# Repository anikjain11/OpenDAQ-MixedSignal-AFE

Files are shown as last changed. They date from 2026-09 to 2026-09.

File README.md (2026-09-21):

# OpenDAQ-AFE: Mixed-Signal Detector Readout & DAQ Pipeline

<div align="center">




[]()

</div>

---

## 🔬 Project Overview

**OpenDAQ-AFE** is an open-source, production-grade mixed-signal data acquisition (DAQ) and detector front-end architecture. Designed for high-energy physics instrumentation, this system bridges microscopic sensor physics to real-time digital signal processing.

It takes a sub-nanosecond, femtocoulomb-level current pulse generated by a particle hit on a semiconductor sensor, processes it through an ultra-low noise analog front-end (AFE), and digitizes the signal via a high-speed path. 

---

## 📐 System Architecture & Signal Chain

    [ Semiconductor Sensor (PIN Diode / 70pF) ]
                           │ 
                           ▼ (1 pC Charge Pulse, ~1ns rise)
    [ Analog Front-End (OPA656 Charge-Sensitive Preamplifier) ]
                           │ 
                           ▼ (-900mV Step, 50us Exponential Decay)
    [ Active CR-RC Pulse Shaper with PZ Cancellation ]
                           │ 
                           ▼ (~720mV Semi-Gaussian shaping peak)
    [ High-Speed Flash ADC & FPGA RTL Engine ]
                           │ 
                           ▼ (Digitized Event Frames)
    [ CERN ROOT / Python Analysis Pipeline ]

---

## 🛠️ Repository Structure

    OpenDAQ-MixedSignal-AFE/
    ├── hardware_kicad/         # 4-Layer PCB schematics, layout (.kicad_pcb), and Gerbers
    ├── simulations_spice/      # Ngspice netlists, subcircuits (.sub), and transient analysis
    │   └── CSP_FrontEnd_Simulation/
    │       ├── opa656.sub      
    │       └── README.md       # Detailed SPICE math and slew-rate bottleneck logs
    ├── results/                # Visual proof and exported documentation
    │   ├── 01_simulations/     # Python-plotted transient response graphs
    │   ├── 02_schematics/      # PDF exports of system architecture
    │   └── 03_pcb_layout/      # 2D routing and 3D board renders
    └── README.md               # Main project overview (You are here)

---

## ⚡ Sub-System 1: Analog Front-End (CSP & Shaper)

### Mathematical Foundation
The Charge-Sensitive Preamplifier (CSP) converts input charge ($Q_{in}$) into a proportional voltage step via feedback capacitance ($C_f = 1\text{ pF}$). To prevent pulse pile-up at high event rates, the 50µs CSP decay tail is compressed using an active shaping amplifier. A Pole-Zero (PZ) cancellation network perfectly counteracts the CSP's discharge time constant.

* **Active Element:** OPA656 Wideband Unity-Gain Stable JFET-Input Op-Amp
* **Detector Capacitance:** 70 pF (PIN Photodiode emulation)
* **PZ Cancellation Resistor:** $R_{pz} = 500\text{ k}\Omega$ 

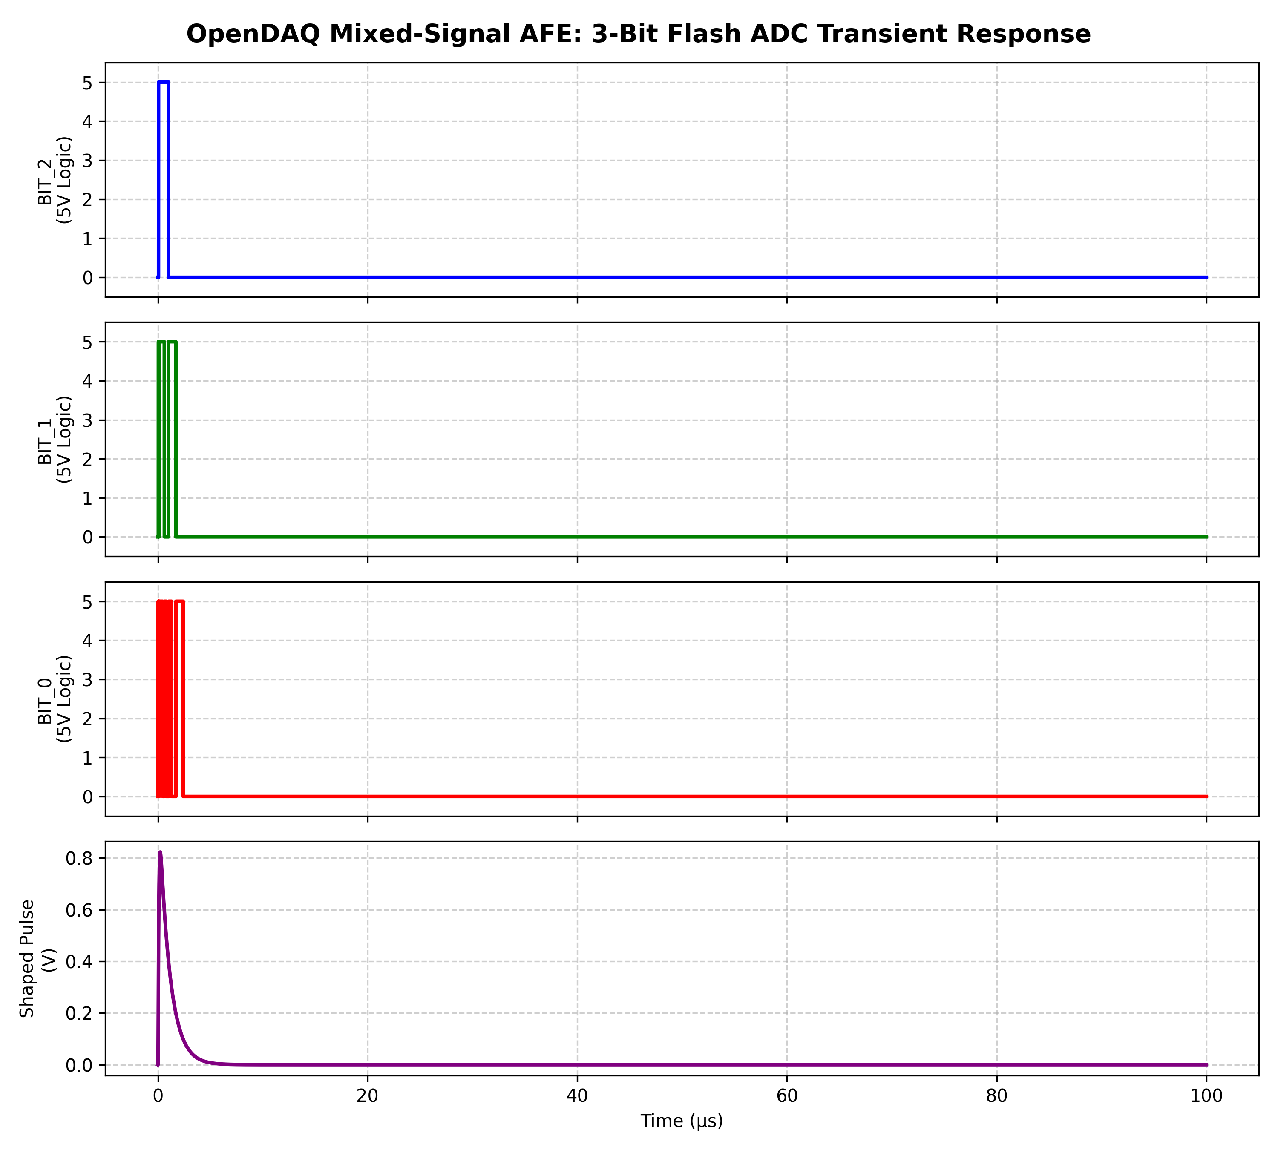
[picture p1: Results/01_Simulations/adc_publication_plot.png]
Transient Response

> *Above: Ngspice transient analysis displaying the shaper compressing the 50µs tail into a clean ~720mV semi-Gaussian peak, triggering the 3-bit Flash ADC logic (111).*
> *Note: For a deep dive into the SPICE slew-rate limitations and behavioral modeling of the ADC, [read the Simulation Notes here](simulations_spice/Simulation_README.md).*

---

## 🖨️ Sub-System 2: Physical Hardware (4-Layer PCB)

To translate the physics into silicon, the AFE was routed onto a strictly constrained, tapeout-ready physical board.

* **Dimensions:** Ultra-compact 16.7mm x 66.5mm footprint.
* **Stackup:** 4-Layer FR-4 (Signal, Ground Plane, Power Plane, Signal) for maximum EMI shielding.
* **Mixed-Signal Isolation:** Strict physical separation between the sensitive analog RF ground planes and the high-speed digital ADC return paths to protect the microvolt-level bias currents.

### Board Renders & Routing
<p align="center">
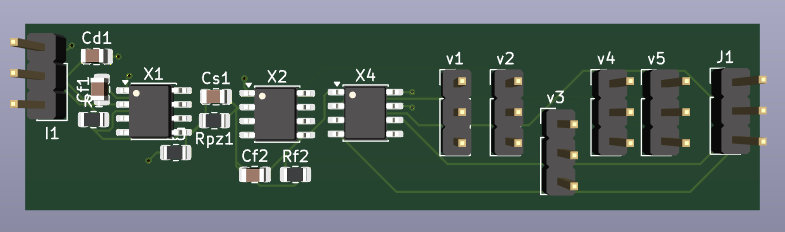
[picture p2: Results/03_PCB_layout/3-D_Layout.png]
3D PCB Render
  
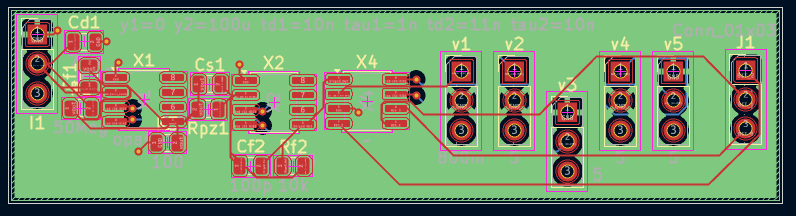
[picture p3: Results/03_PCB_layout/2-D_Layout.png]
2D Routing
  
</p>

---

## 📜 License
This hardware design and its associated software simulations are licensed under the **CERN Open Hardware Licence v2.0 - Strongly Reciprocal (CERN-OHL-S)**. See the LICENSE file for details.

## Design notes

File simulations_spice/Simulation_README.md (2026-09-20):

## 1. Charge-Sensitive Preamplifier (CSP) Front-End

### Objective
Design an ultra-low bias current analog front-end to integrate a 1 pC fast current pulse (simulating a particle strike on a 70 pF PIN photodiode) into a measurable voltage step.

### Architecture & Math
* **Op-Amp:** OPA656 (JFET input selected for low current noise).
* **Gain Stage:** Feedback capacitor $C_f = 1\text{ pF}$ designed to yield a step voltage of -1V for a 1 pC input charge.
* **Discharge Path:** Feedback resistor $R_f = 50\text{ M}\Omega$ placed in parallel to prevent saturation, setting a continuous discharge time constant of $\tau = 50\ \mu\text{s}$.

### Analysis
Transient analysis confirms the theoretical derivations. The initial charge injection drives the output to approximately -900 mV. At 50 µs, the signal decays to -330 mV, perfectly aligning with the theoretical $e^{-1}$ discharge curve.

---

## 2. Mixed-Signal Verification: 3-Bit Flash ADC

### Simulation Objective
* **Goal:** Validate the transient response of a 3-bit Flash ADC designed for the OpenDAQ Analog Front-End.
* **Input Signal:** A baseline-restored, 720 mV semi-Gaussian particle pulse peaking in roughly 1 to 2 microseconds.
* **Architecture:** An 8-resistor reference ladder (0V to 800mV) feeding 7 parallel comparators and custom digital logic bridges.

### Bottleneck 1: Component Slew Rate Limits
* **The Problem:** Initial simulations utilizing legacy LM741 op-amps resulted in a dead 0V digital output.
* **The Root Cause:** The LM741 possesses a slew rate of just 0.5V/µs. Swinging its output to trigger digital logic thresholds required upwards of 30 microseconds.
* **The Analysis:** The fast sub-microsecond particle pulse peaked and vanished long before the analog comparators could physically react.

### Bottleneck 2: Open-Loop Macro-Model Failure
* **The Problem:** Upgrading the comparators to the high-speed OPA656 (290V/µs slew rate) still yielded flatline results.
* **The Root Cause:** Vendor SPICE macro-models are mathematically optimized for closed-loop linear amplification. Forcing seven complex macro-models into an open-loop comparator topology caused internal saturation and engine convergence failures.

### The Solution: Behavioral Modeling & Visualization
* **Simulation Fix:** Replaced physical IC macro-models with mathematical arbitrary behavioral sources (`B` sources) acting as ideal comparators. This successfully decoupled the analog SPICE convergence constraints from the digital logic validation.
* **Data Extraction:** KiCad's native plotter struggled to auto-scale instantaneous 0V to 5V logic transitions. Raw transient data was exported via CSV and processed through a custom Python script (Pandas/Matplotlib) to generate a stacked, publication-ready visualization.

### Final Transient Response
ADC Transient Response
*(Image: OpenDAQ AFE digitizing a 1 pC equivalent simulated particle hit)*

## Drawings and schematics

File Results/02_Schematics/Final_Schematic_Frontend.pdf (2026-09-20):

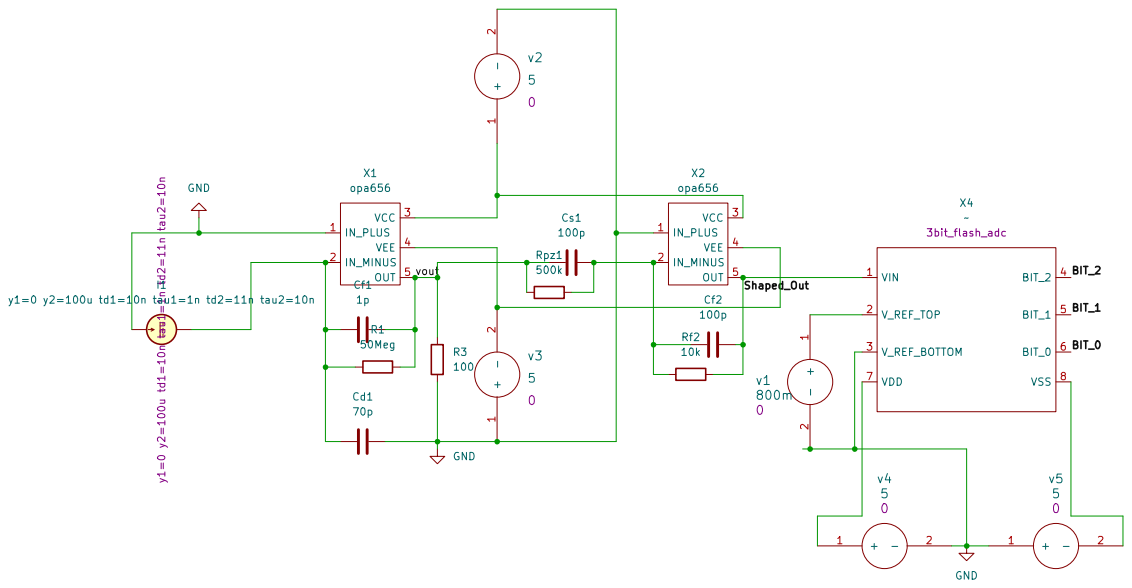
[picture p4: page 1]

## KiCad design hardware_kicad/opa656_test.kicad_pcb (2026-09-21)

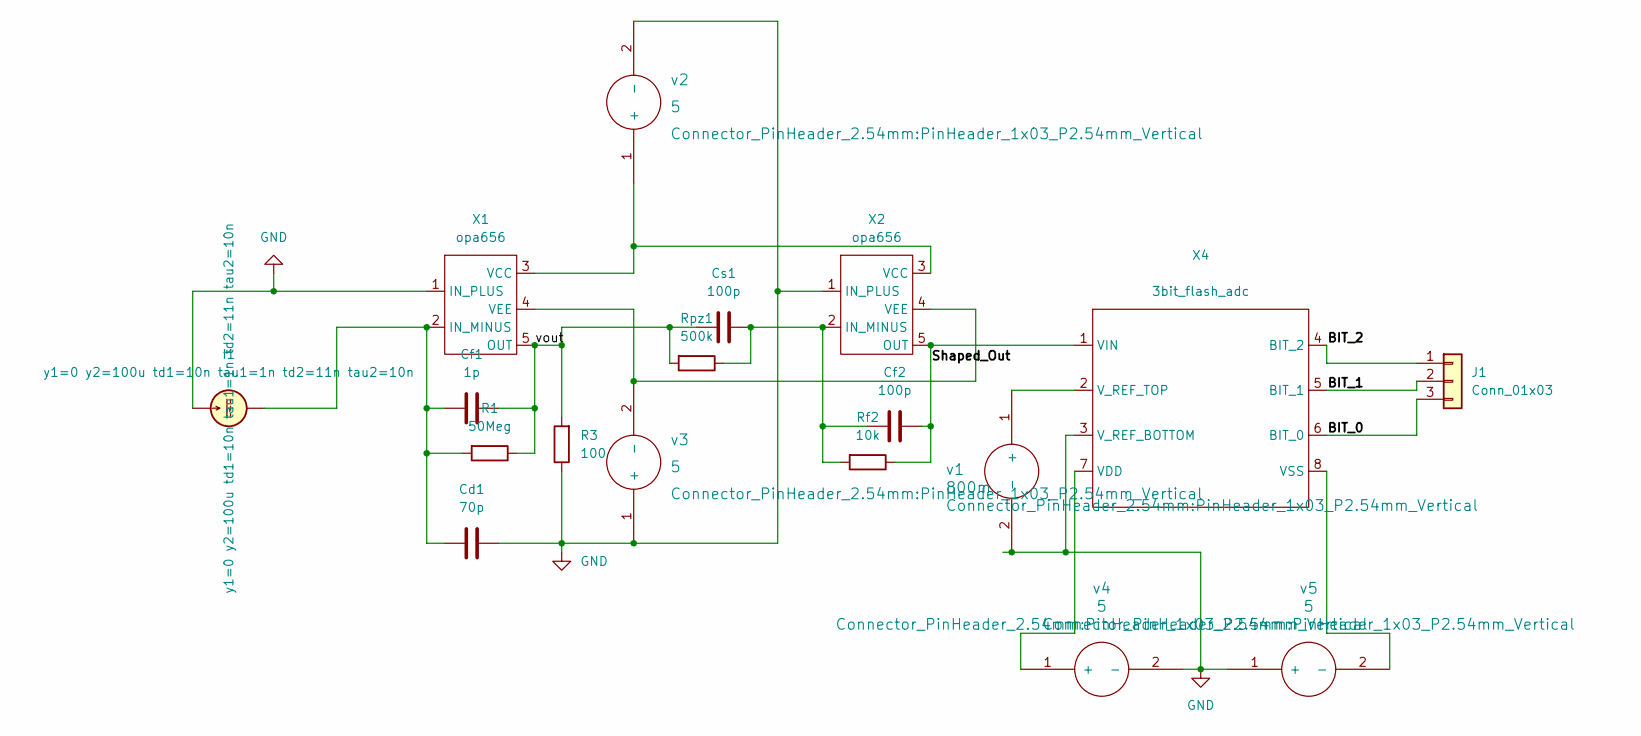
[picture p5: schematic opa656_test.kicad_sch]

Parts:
Cd1: 70p; C_0805_2012Metric
Cf1: 1p; C_0805_2012Metric
Cf2: 100p; C_0805_2012Metric
Cs1: 100p; C_0805_2012Metric
I1: y1=0 y2=100u td1=10n tau1=1n td2=11n tau2=10n; PinHeader_1x03_P2.54mm_Vertical
J1: Conn_01x03; PinHeader_1x03_P2.54mm_Vertical
R1: 50Meg; R_0805_2012Metric
R3: 100; R_0805_2012Metric
Rf2: 10k; R_0805_2012Metric
Rpz1: 500k; R_0805_2012Metric
X1, X2: opa656; SOIC-8_3.9x4.9mm_P1.27mm
X4: SOIC-8_3.9x4.9mm_P1.27mm
v1: 800m; PinHeader_1x03_P2.54mm_Vertical
v2, v3, v4, v5: 5; PinHeader_1x03_P2.54mm_Vertical

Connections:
/BIT_0: J1.3, X4.6 (BIT_0)
/BIT_1: J1.2, X4.5 (BIT_1)
/BIT_2: J1.1, X4.4 (BIT_2)
/Shaped_Out: Cf2.2, Rf2.1, X2.5 (OUT), X4.1 (VIN)
/vout: Cf1.2, Cs1.1, R1.1, R3.2, Rpz1.2, X1.5 (OUT)
GND: Cd1.2, I1.1, R3.1, X1.1 (IN_PLUS), X2.1 (IN_PLUS), X4.3 (V_REF_BOTTOM), v1.2 (-), v2.2 (-), v3.1 (+), v4.2 (-), v5.1 (+)
unnamed: Cd1.1, Cf1.1, I1.2, R1.2, X1.2 (IN_MINUS)
unnamed: X1.3 (VCC), X2.3 (VCC), v2.1 (+)
unnamed: X1.4 (VEE), X2.4 (VEE), v3.2 (-)
unnamed: Cf2.1, Cs1.2, Rf2.2, Rpz1.1, X2.2 (IN_MINUS)
unnamed: X4.7 (VDD), v4.1 (+)
unnamed: X4.8 (VSS), v5.2 (-)
unnamed: X4.2 (V_REF_TOP), v1.1 (+)

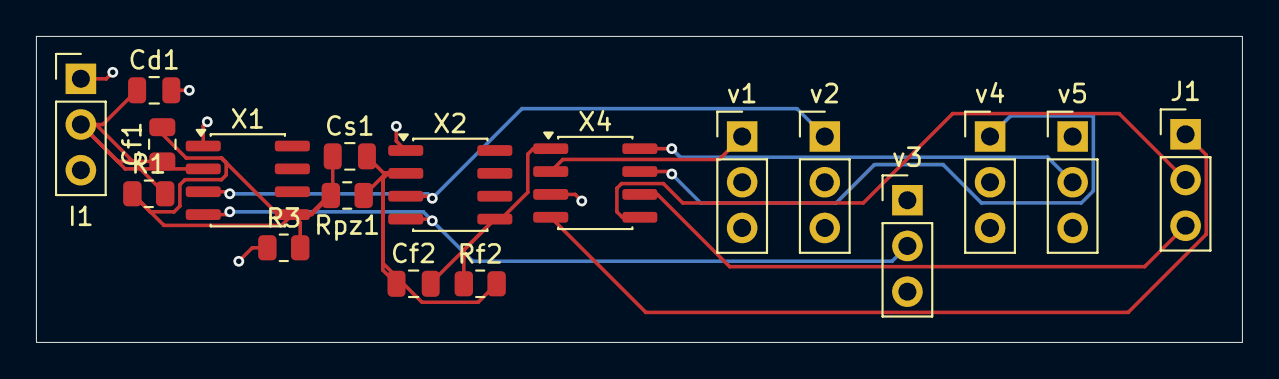
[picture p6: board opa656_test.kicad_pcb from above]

Board: 4 copper layers, 67.0 x 17.0 mm, 18 parts (0 on the bottom side), 13 nets.

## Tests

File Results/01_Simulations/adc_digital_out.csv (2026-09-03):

time | V(/BIT_0) | V(/BIT_1) | V(/BIT_2) | V(/Shaped_Out)
0 | 0 | 0 | 0 | 0
1e-10 | 0 | 0 | 0 | 0
2e-10 | 0 | 0 | 0 | 0
4e-10 | 0 | 0 | 0 | 0
8e-10 | 0 | 0 | 0 | 0
1.6e-09 | 0 | 0 | 0 | 0
3.2e-09 | 0 | 0 | 0 | 0
6.4e-09 | 0 | 0 | 0 | 0
8.00639e-09 | 0 | 0 | 0 | 0
8.96945e-09 | 0 | 0 | 0 | 0
9.52778e-09 | 0 | 0 | 0 | 0
9.85343e-09 | 0 | 0 | 0 | 0
1.00432e-08 | 0 | 0 | 0 | 6.76656e-07
1.01527e-08 | 0 | 0 | 0 | 2.23435e-06
1.02203e-08 | 0 | 0 | 0 | 2.96838e-06
1.02896e-08 | 0 | 0 | 0 | 2.62849e-06
1.0379e-08 | 0 | 0 | 0 | 7.76301e-07
1.04788e-08 | 0 | 0 | 0 | -3.60166e-06
1.06166e-08 | 0 | 0 | 0 | -1.41215e-05
1.07521e-08 | 0 | 0 | 0 | -2.99234e-05
1.08877e-08 | 0 | 0 | 0 | -5.14162e-05
1.10139e-08 | 0 | 0 | 0 | -7.65829e-05
1.11842e-08 | 0 | 0 | 0 | -0.000118371
1.13787e-08 | 0 | 0 | 0 | -0.000175667
1.16395e-08 | 0 | 0 | 0 | -0.000265001
1.19575e-08 | 0 | 0 | 0 | -0.000386739
1.23362e-08 | 0 | 0 | 0 | -0.000536902
1.275e-08 | 0 | 0 | 0 | -0.000688295
1.32881e-08 | 0 | 0 | 0 | -0.000829385
1.39352e-08 | 0 | 0 | 0 | -0.000859597
1.47921e-08 | 0 | 0 | 0 | -0.000563974
1.58966e-08 | 0 | 0 | 0 | 0.000533814
1.74688e-08 | 0 | 0 | 0 | 0.00371411
1.98928e-08 | 0 | 0 | 0 | 0.0124834
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

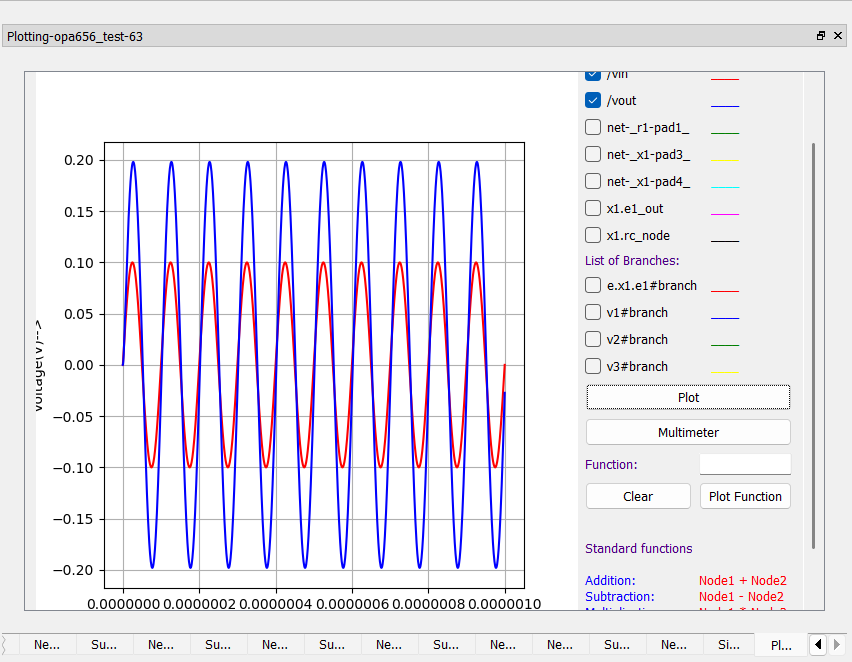
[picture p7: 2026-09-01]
simulations_spice/CSP_FrontEnd_Simulation/amplifier_result_OPA656.png

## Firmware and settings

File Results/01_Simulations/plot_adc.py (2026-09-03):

import pandas as pd
import matplotlib.pyplot as plt

# 1. Load the exported KiCad CSV
df = pd.read_csv('adc_digital_out.csv', sep=';')
df.columns = df.columns.str.strip()
df = df.apply(pd.to_numeric, errors='coerce')

# Convert time to microseconds
time = df.iloc[:, 0] * 1e6  

# 2. Set up a 4-row stacked layout
fig, axs = plt.subplots(4, 1, figsize=(10, 9), sharex=True)
fig.suptitle('OpenDAQ Mixed-Signal AFE: 3-Bit Flash ADC Transient Response', fontsize=14, fontweight='bold')

# 3. Plot BIT_2 (MSB)
axs[0].plot(time, df['V(/BIT_2)'], color='blue', linewidth=2)
axs[0].set_ylabel('BIT_2\n(5V Logic)')
axs[0].set_ylim(-0.5, 5.5)
axs[0].grid(True, linestyle='--', alpha=0.6)

# 4. Plot BIT_1
axs[1].plot(time, df['V(/BIT_1)'], color='green', linewidth=2)
axs[1].set_ylabel('BIT_1\n(5V Logic)')
axs[1].set_ylim(-0.5, 5.5)
axs[1].grid(True, linestyle='--', alpha=0.6)

# 5. Plot BIT_0 (LSB)
axs[2].plot(time, df['V(/BIT_0)'], color='red', linewidth=2)
axs[2].set_ylabel('BIT_0\n(5V Logic)')
axs[2].set_ylim(-0.5, 5.5)
axs[2].grid(True, linestyle='--', alpha=0.6)

# 6. Plot the Analog Input Pulse
axs[3].plot(time, df['V(/Shaped_Out)'], color='purple', linewidth=2)
axs[3].set_ylabel('Shaped Pulse\n(V)')
axs[3].set_xlabel('Time (µs)')
axs[3].grid(True, linestyle='--', alpha=0.6)

# Save the final high-res image
plt.tight_layout()
plt.savefig('adc_publication_plot.png', dpi=300)
print("Complete 4-panel publication plot successfully saved as adc_publication_plot.png!")

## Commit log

2026-09-03 complete phase 1 mixed-signal simulation and behavioral modeling
    [adc_digital_out.csv, opa656_test.kicad_sch]
2026-09-03 Fix image path in Simulation_README.md
    Updated image path for ADC Transient Response in README.
2026-09-21 Modifications Made
    [opa656_test-B_Cu.gbl, opa656_test-B_Mask.gbs, opa656_test-B_Paste.gbp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]

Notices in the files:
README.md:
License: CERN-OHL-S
